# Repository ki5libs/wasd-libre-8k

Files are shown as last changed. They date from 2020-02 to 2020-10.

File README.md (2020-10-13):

View this project on [CADLAB.io](https://cadlab.io/project/23397). 

# WASD-libre-8K

FPGA-based keyboard controller

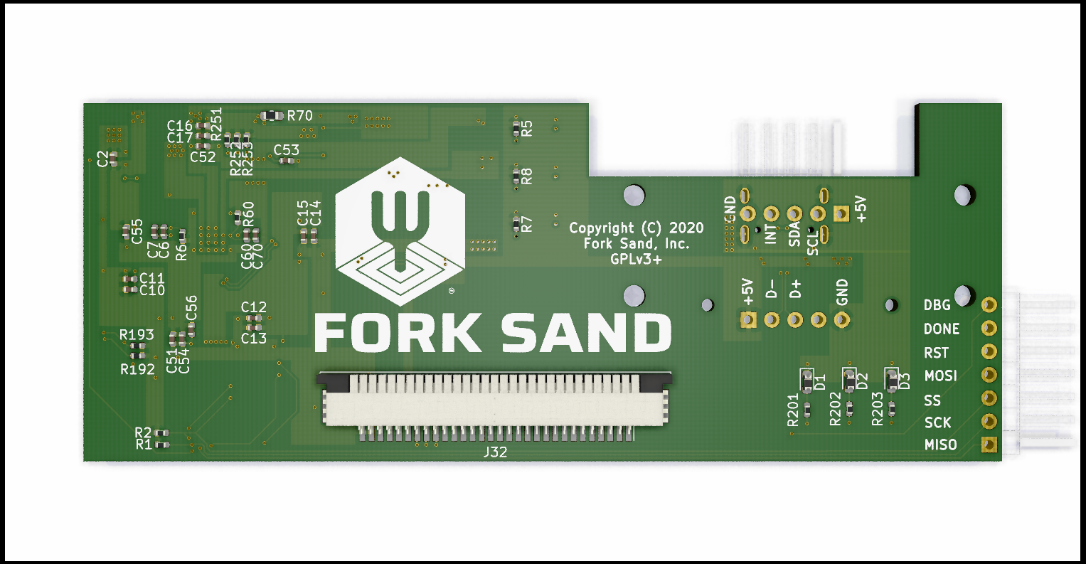
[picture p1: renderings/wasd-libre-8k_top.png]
Rendering of top layer with ANSI

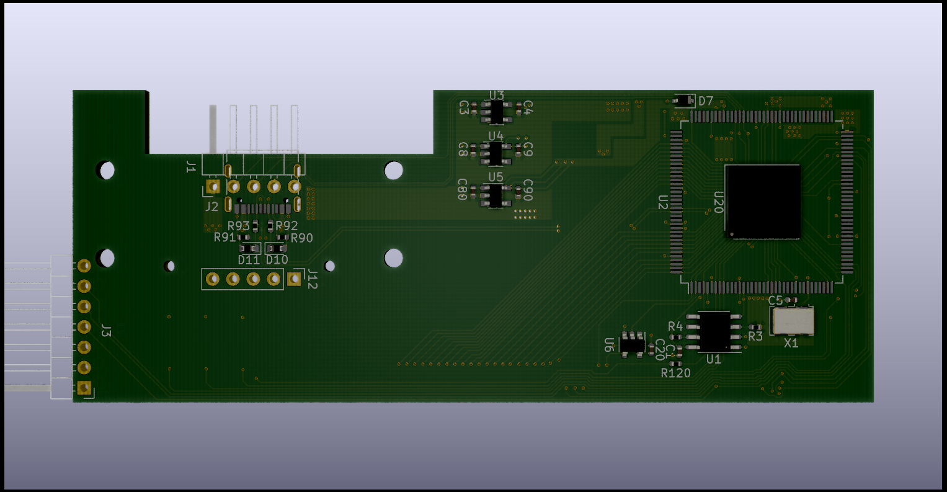
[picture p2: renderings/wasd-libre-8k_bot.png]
Rendering of bot layer with ANSI


## Goal Features
 - open-source firmware and toolchain
 - QMK-compatibility (patches are planning)
 - WASD-keyboard compatibility
 - Mechanical compatibility with existing popular 80% keyboards (i.e XD87 from KRepublic)
 - controlling keyboard backlight
 - controlling keyboard RGB-highlight
 - I2C (ready) and USB (planning) interfaces
 
 The work is in progress...

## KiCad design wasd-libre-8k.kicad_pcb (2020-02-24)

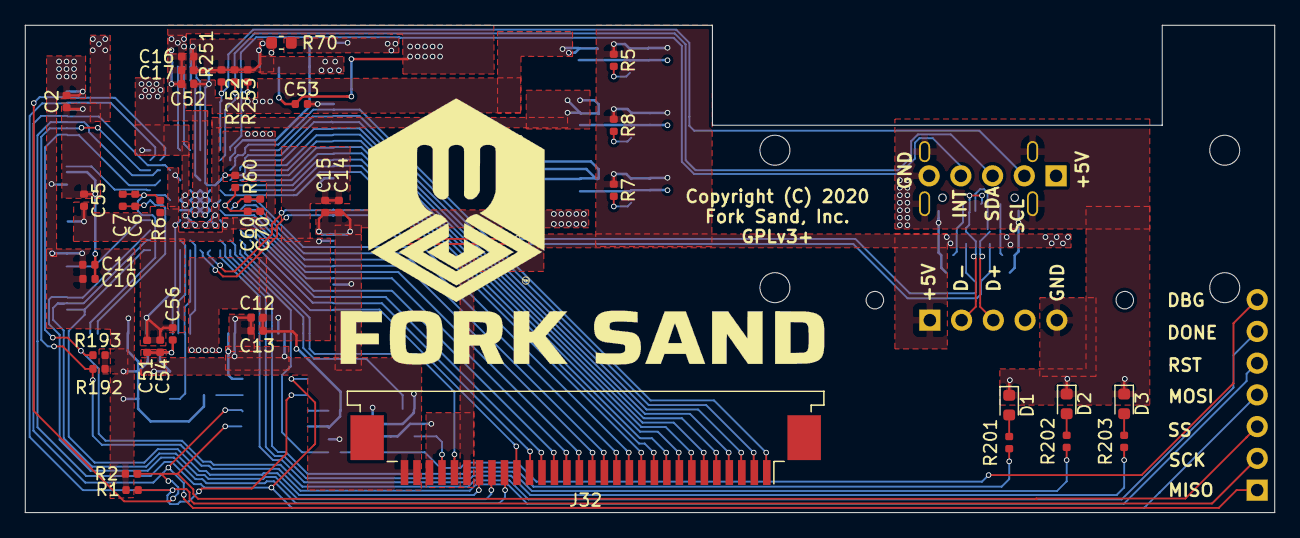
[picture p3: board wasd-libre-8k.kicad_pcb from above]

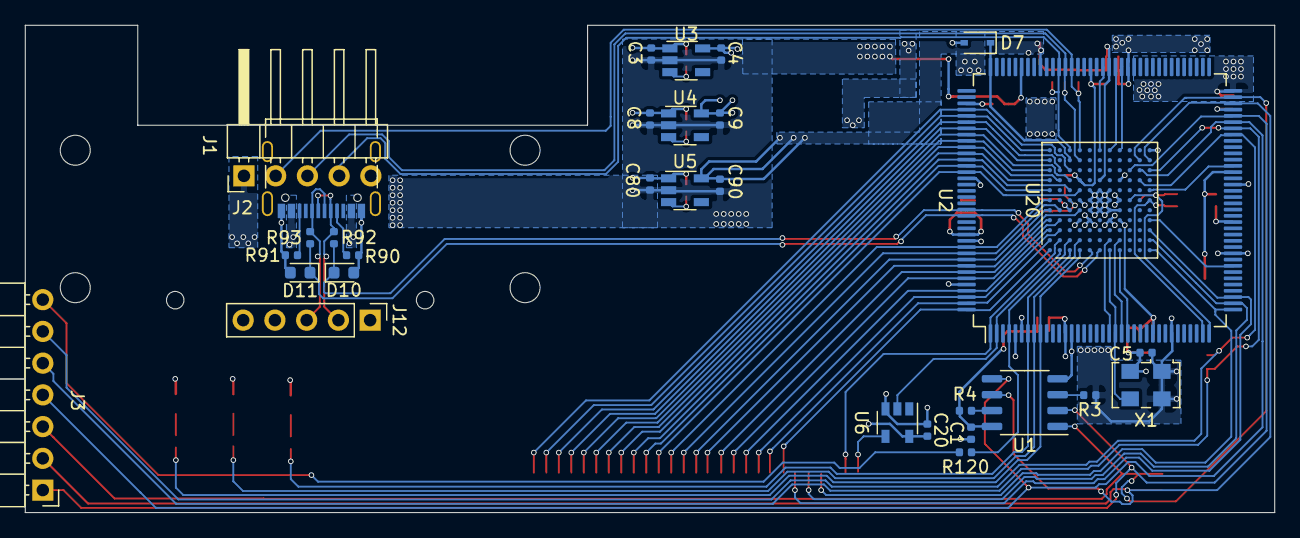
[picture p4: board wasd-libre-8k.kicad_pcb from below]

Board: 2 copper layers, 100.0 x 39.0 mm, 70 parts (31 on the bottom side), 74 nets.

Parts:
C1, C2, C5, C6, C10, C11, C12, C13, C14, C15, C16, C17, C20, C52, C53, C54, C55, C60: 0.1 uF; C_0402_1005Metric
C3, C4, C8, C9, C80, C90: 1 uF; C_0402_1005Metric
C7, C51, C70: 10 uF; C_0402_1005Metric
C56: 0.01 uF; C_0402_1005Metric
D1, D2, D3: TO-1608BC-MYF; D_0603_1608Metric
D7: 1PS76SB10; D_SOD-323
D10, D11: PGB1010603NRHF; D_0603_1608Metric
J1: Conn_01x05; PinHeader_1x05_P2.54mm_Horizontal
J2: USB_C_Receptacle_USB2.0; USB_C_Receptacle_Palconn_UTC16-G
J3: Conn_01x07; PinHeader_1x07_P2.54mm_Horizontal
J12: Conn_01x05; PinHeader_1x05_P2.54mm_Vertical
J32: Conn_01x30; TE_3-84953-0_1x30-1MP_P1.0mm_Horizontal
R1, R2, R3, R4, R5, R7, R8, R192, R193, R251, R252, R253: 10K; R_0402_1005Metric
R6, R60: 100; R_0402_1005Metric
R70: 0; R_0603_1608Metric
R90, R91: 5K1; R_0402_1005Metric
R92, R93: 22; R_0402_1005Metric
R120: 300; R_0402_1005Metric
R201, R202, R203: 200; R_0402_1005Metric
U1: MX25R3235FM1xx1; SOP-8_3.9x4.9mm_P1.27mm
U2: ICE40HX1K-TQ144; TQFP-144_20x20mm_P0.5mm
U3: NCV8114ASN120T1G; TSOT-23-5
U4: NCV8114ASN330T1G; TSOT-23-5
U5: NCV8114ASN180T1G; TSOT-23-5
U6: SN74LVC1G14DBV; SOT-23-5
U20: ICE40HX8K-BG121; BGA-121_9.0x9.0mm_Layout11x11_P0.8mm_Ball0.4mm_Pad0.35mm_NS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
X1: XO53, 12 MHz; Oscillator_SMD_EuroQuartz_XO53-4Pin_5.0x3.2mm

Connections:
+1V2: C4.2, C51.2, C52.2, C53.2, C54.2, C55.2, C56.2, R6.1, R60.1, U2.27, U2.51, U2.92, U2.111, U3.5, U20.D4, U20.D8, U20.H4, U20.H8
+3V3: C1.2, C2.2, C5.2, C9.2, C10.2, C11.2, C12.2, C13.2, C14.2, C15.2, D7.2, R1.1, R2.1, R3.1, R4.1, R70.2, R192.2, R193.2, U1.8, U2.6, U2.30, U2.46, U2.57, U2.72, U2.123, U2.133, U4.5, U20.D6, U20.E4, U20.G4, U20.H6, U20.L11, X1.1, X1.4
+5V: C3.2, C8.2, C20.2, C80.2, J1.1, J2.A4, J2.A9, J2.B4, J2.B9, J12.1, J32.25, J32.28, R5.1, R7.1, R8.1, U3.1, U4.1, U5.1, U6.5
+VSW: C16.2, C17.2, C90.2, R70.1, R251.1, R252.1, R253.1, U2.89, U2.100, U5.5, U20.F8
/CLK: U2.21, U20.G1, X1.3
/COL0: J32.17, U2.139, U20.B4
/COL1: J32.18, U2.141, U20.A3
/COL2: J32.19, U2.142, U20.B3
/COL3: J32.20, U2.143, U20.A2
/COL4: J32.21, U2.144, U20.A1
/COL5: J32.22, U2.39, U20.L3
/COL6: J32.23, U2.38, U20.L2
/COL7: J32.24, U2.37, U20.L1
/D+: J2.A6, J2.B6, J12.3, R93.2
/D-: J2.A7, J2.B7, J12.2, R92.2
/DEBUG: R120.1, U2.4, U20.C2
/DEBUG_LED1: R201.1, U2.7, U20.C1
/DEBUG_LED2: R202.1, U2.8, U20.D2
/DEBUG_LED3: R203.1, U2.9, U20.D1
/DEBUG_TX: J3.7, R120.2
/GNDPLL0: C6.1, C7.1, U2.35, U20.L6
/I2C0_SCL: J1.2, R251.2, U2.95, U20.D11
/I2C0_SDA: J1.3, R252.2, U2.96, U20.D10
/ICE_CDONE: J3.6, R193.1, U2.65, U20.K8
/ICE_CRST_B: J3.5, R192.1, U2.66, U20.L9
/ICE_MISO: J3.1, U1.2, U2.68, U20.J9
/ICE_MOSI: J3.4, U1.5, U2.67, U20.K9
/ICE_SCK: J3.2, R1.2, U1.6, U2.70, U20.L10
/ICE_SS: J3.3, R2.2, U1.1, U2.71, U20.K10
/INTERRUPT: J1.4, R253.2, U2.97, U20.C11
/PWM_OUT: J32.26, U2.1, U20.B2
/RGB_DRV: U2.2, U6.2, U20.B1
/RGB_OUT: J32.27, U6.4
/ROW0: J32.1, U2.112, U20.C9
/ROW1: J32.2, U2.113, U20.A11
/ROW2: J32.3, U2.114, U20.B9
/ROW3: J32.4, U2.115, U20.A10
/ROW4: J32.5, U2.116, U20.C8
/ROW5: J32.6, U2.117, U20.A9
/ROW6: J32.7, U2.118, U20.B8
/ROW7: J32.8, U2.119, U20.A8
/ROW8: J32.9, U2.120, U20.C7
/ROW9: J32.10, U2.121, U20.A7
/ROW10: J32.11, U2.122, U20.D7
/ROW11: J32.12, U2.134, U20.A6
/ROW12: J32.13, U2.135, U20.B5
/ROW13: J32.14, U2.136, U20.A5
/ROW14: J32.15, U2.137, U20.D5
/ROW15: J32.16, U2.138, U20.A4
/SPR1: U2.23, U20.H1
/SPR2: U2.22, U20.H2
/SPR3: U2.20, U20.G2
/SPR4: U2.44, U20.L4
/SPR5: U2.60, U20.L7
/SPR6: U2.87, U20.H11
/SPR7: U2.88, U20.G11
/SPR8: U2.90, U20.F11
/USB_D+: D11.1, R93.1, U2.129, U20.F1
/USB_D-: D10.1, R92.1, U2.128, U20.E1
/VCCPLL0: C6.2, C7.2, R6.2, U2.36, U20.J6
/VPP_2V5: D7.1, U2.108, U20.C10
GND: C1.1, C2.1, C3.1, C4.1, C5.1, C8.1, C9.1, C10.1, C11.1, C12.1, C13.1, C14.1, C15.1, C16.1, C17.1, C20.1, C51.1, C52.1, C53.1, C54.1, C55.1, C56.1, C80.1, C90.1, D1.1, D2.1, D3.1, D10.2, D11.2, J1.5, J2.A1, J2.A12, J2.B1, J2.B12, J2.S1, J12.5, J32.29, J32.30, R90.1, R91.1, U1.4, U2.5, U2.13, U2.14, U2.59, U2.69, U2.86, U2.103, U2.132, U2.140, U3.2, U4.2, U5.2, U6.3, U20.E5, U20.E6, U20.E7, U20.F5, U20.F6, U20.F7, U20.G5, U20.G6, U20.G7, U20.H5, X1.2
unnamed: C60.1, C70.1, U20.C5
unnamed: C60.2, C70.2, R60.2, U20.C6
unnamed: D1.2, R201.2
unnamed: D2.2, R202.2
unnamed: D3.2, R203.2
unnamed: J2.A5, R90.2
unnamed: J2.B5, R91.2
unnamed: R3.2, U1.3
unnamed: R4.2, U1.7
unnamed: R5.2, U3.3
unnamed: R7.2, U5.3
unnamed: R8.2, U4.3

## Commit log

2020-01-11 Test version production
    [wasd-libre-8k.kicad_pcb, wasd-libre-8k.sch]
2020-01-26 Some USB changes
    [wasd-libre-8k.kicad_pcb, wasd-libre-8k.sch]
2020-01-26 Fix mechanical dimensions, adding spare lines
    [wasd-libre-8k.kicad_pcb, wasd-libre-8k.sch]
2020-01-27 Silkscreen sign for prog port
    [wasd-libre-8k.kicad_pcb]
2020-02-05 RGB LED level converter added
    [wasd-libre-8k.kicad_pcb, wasd-libre-8k.sch]
2020-02-12 J32 (32 pins) replaced by 30 pins for using TE connector
    [wasd-libre-8k.kicad_pcb, wasd-libre-8k.sch]
2020-02-20 Adding some silkscreen, moved I2C lines, added additional holes for USB
    [wasd-libre-8k.kicad_pcb, wasd-libre-8k.sch]
2020-02-21 Old FPC connector removed
2020-02-21 Reworked for production cost decrease
    [wasd-libre-8k.kicad_pcb]

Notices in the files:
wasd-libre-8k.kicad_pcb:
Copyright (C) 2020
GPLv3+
